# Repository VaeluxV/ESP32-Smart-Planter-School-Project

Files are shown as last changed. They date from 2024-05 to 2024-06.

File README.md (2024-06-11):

# ESP32 Smart Planter
## Hardware info
### Required Hardware:
* ESP32 Devkit (30-pins)
* Soil moisture sensor
* PN532 rfid reader
* Passive buzzer
* LDR
* Ds18b20 Soil temperature sensor
* Water Level Sensor
* Bme280
* 5V 4-channel relay module (a 2-channel module can also be used if you do not plan to add more hardware yourself)
* I2C LCD (min. 4 lines, 20 characters per line)
* Wire
### Optional hardware:
* Custom PCB (gerber files can be found under [`/CustomPCB/Gerber`](https://github.com/VaeluxV/ESP32-Smart-Planter-School-Project/tree/main/CustomPCB/Gerber) and eagle schematics under [`/Eagle/ESP-Planter`](https://github.com/VaeluxV/ESP32-Smart-Planter-School-Project/tree/main/Eagle/ESP-Planter))

## Software info

### Required software:
* Arduino IDE or VS Code (Platformio) (originally developed for/using Platformio)

### Required libraries:
* SPI
* Adafruit_PN532
* Wire
* LiquidCrystal_I2C
* Adafruit_Sensor
* Adafruit_BME280
* FastLED
* OneWire
* DallasTemperature
* WiFi
* PubSubClient
* freertos/FreeRTOS
* freertos/task

### The code:
You can find the code for the ESP32 under [`/src/main.cpp`](https://github.com/VaeluxV/ESP32-Smart-Planter-School-Project/blob/main/src/main.cpp)

---

## Other info

This project works using Grafana, InfluxDB & MQTT installed on any device such as a Raspberry Pi. You can remove the Grafana & InfluxDB if you do not need to store any data but it is not recommended because I have not tested the full functionality without these programs. MQTT is required if you do not modify any code.

Make sure to enter your WiFi and MQTT details when uploading this code to your ESP32 or it won't work!

MQTT settings can be found at line 18-21 and WiFi settings can be found at line 32-33.
Other configurable settings can also be found near the top of the code. This can be used if your LCD has a different I2C adress (line 44) for example.

The InfluxDB connection requires a database names `planter_readings` to be present so make sure to make that before starting the MQTT bridge!

Connections schematic (default config):
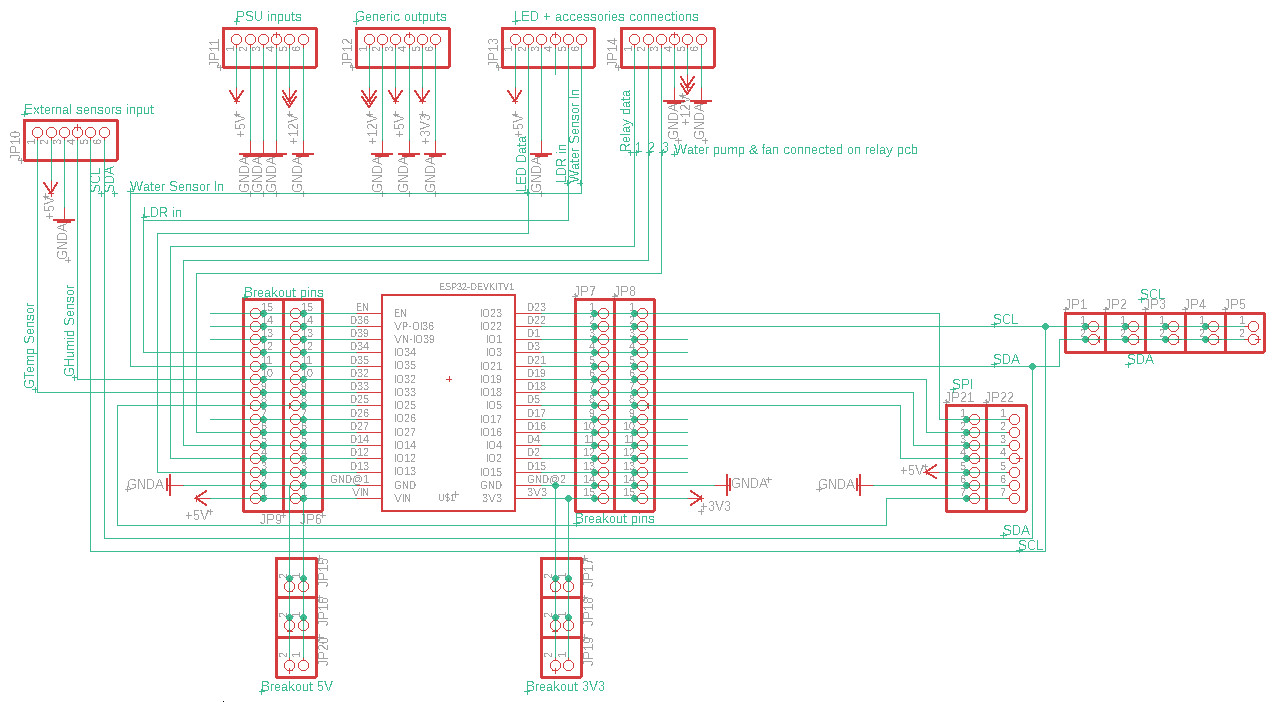
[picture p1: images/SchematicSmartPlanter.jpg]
Image of the schematic

Please note that the 12v & 5v connections are external connections coming from a 12v PSU (& buck converter for the 5v) while the 3.3v is delivered by the ESP32's internal power conversion.

---

### Relays and 12v components
The 5v relay module, 12v fan & 12v water pump are not shown in this schematic but have to be connected too. The fan is connected to relay channel 1, while the pump is connected on channel 2. All of these share a common ground with the esp32 (through the buck converter).

### Debugging connection
Debugging can be done over serial (9600 baud) using the USB connection. Make sure to still plug in the PSU as otherwise there will not be enough power to run everything and the ESP32 will possibly fail to boot properly!

---

You are free to open issues if you have any questions about something not documented here or otherwise not mentioned.

GLHF!

~ Vaelux

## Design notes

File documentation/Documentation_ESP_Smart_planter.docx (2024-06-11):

# ESP Smart Planter – Documentation

Below are pictures of the custom PCB

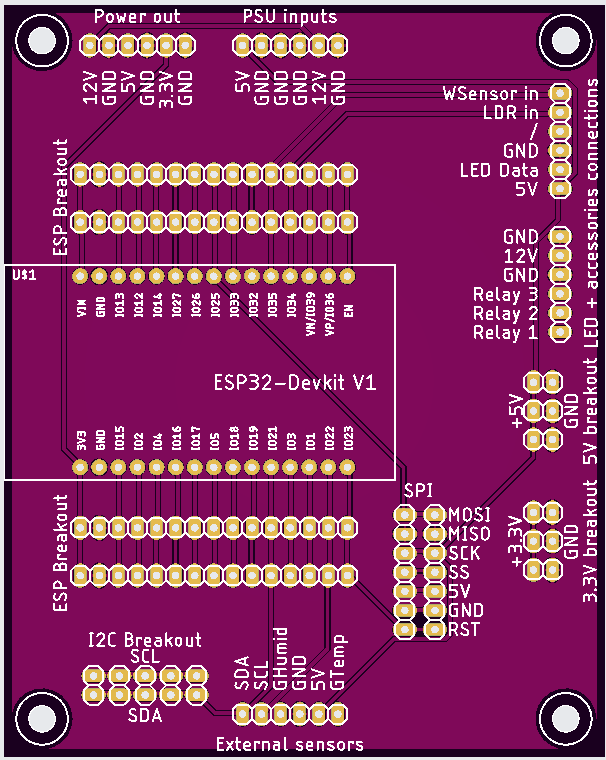
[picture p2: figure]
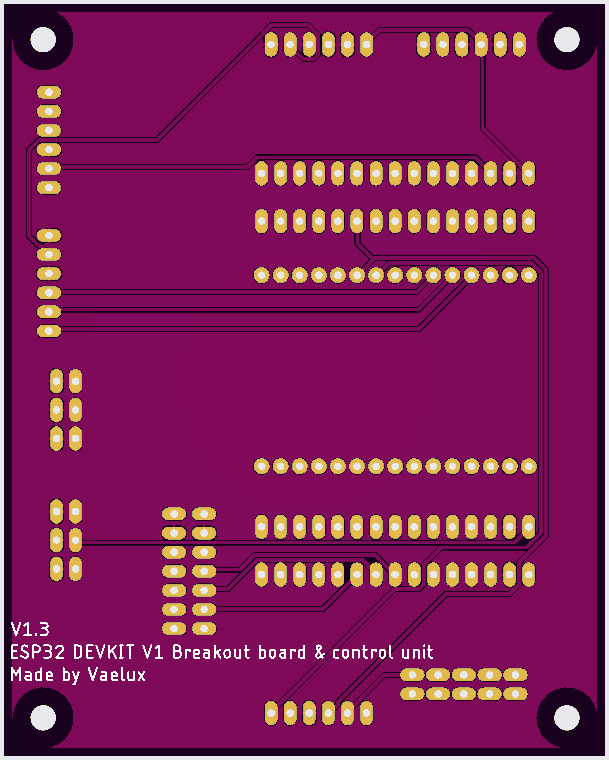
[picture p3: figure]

# Hardware:

- ESP32 Devkit v1 (30 pins)
- PN532 RFID reader
- LDR
- (Capacitive) soil moisture sensor
- I2C 20x4 LCD
- Passive buzzer (or speaker)
- Ds18b20 soil temperature sensor
- BME280
- WS2812B LED (COB) strip
- 4-channel (5v) relay module
- Water pump (12v)
- Fan (12v)
- Power supply (12v)
- Step-down buck converter (12 -> 5v or a variable variant if it can output 5v)
- Wires

# The software:

- Grafana
- InfluxDB
- Python (MQTT -> InfluxDB)
- C++ firmware (for ESP32)

# The Grafana setup

In Grafana we add the data source ‘InfluxDB’ using the created credentials and localhost because the database is running on the same device as the Grafana server.

We can then use graphs to display the temperatures and light values as well as use labels to display statuses of, for example, the fan or lights.

The ESP32 sends the following data:

- Air temperature
- Soil temperature
- Soil moisture
- Light level
- Water level
- Fan status
- Lights status
- Pump Status
- Current target (which plant)

All these datapoints are named appropriately in the influxdb.

# Installing the software and hardware

You can flash the ESP32 using PlatformIO or the Arduino IDE.
Make sure to have all the required libraries installed!

All the required libraries are listed at the top of the C++ code.

If you are unsure of what pins to connect the sensors to, refer to the code or the provided schematic to see what sensors connect to which pins.

Please make sure to change the WiFi SSID, Password & MQTT details BEFORE flashing the firmware to the board!
These can be found near the top of the code with the appropriately defined variables “WIFI_SSID”, “WIFI_PASSWORD”, “mqtt_server”, “mqtt_port”, “mqtt_username” & “mqtt_password”.

If you connect your sensors to other pins, you can change those too. All sensors are defined somewhere at the top portion of the code.

I recommend you either solder screw terminals to the PCB or solder wires that connect the sensors to the PCB, any other (semi-) permanent way is fine too except for breadboards as the tend to get some bad connections or disconnected wires sometimes.

# Important info:

Please refer to the sensor datasheets as some sensors should not be connected to the input of the ESP32 directly but instead need a pullup resistor or other special adjustments.
These resistors are not shown in the schematic but are required to be present for the planter to work properly.

If your fan is not 12v but instead a 5v fan you can use the positive from the buck converter instead of the 12v wire, so you don’t blow up your fan motor.

Refer to the documentation of each service such as Grafana or MQTT on how to set it up.

If the ESP32 is no longer sending data, please check if your WiFi network is still available. Unplug the ESP32 immediately if it gets wet! If the ESP32 is unresponsive, unplug wait a few moments and plug it in again to force it to reboot and reconnect.

Schematics and other info can be found on the GitHub repository, please refer to the ReadMe file on there for the locations of these.

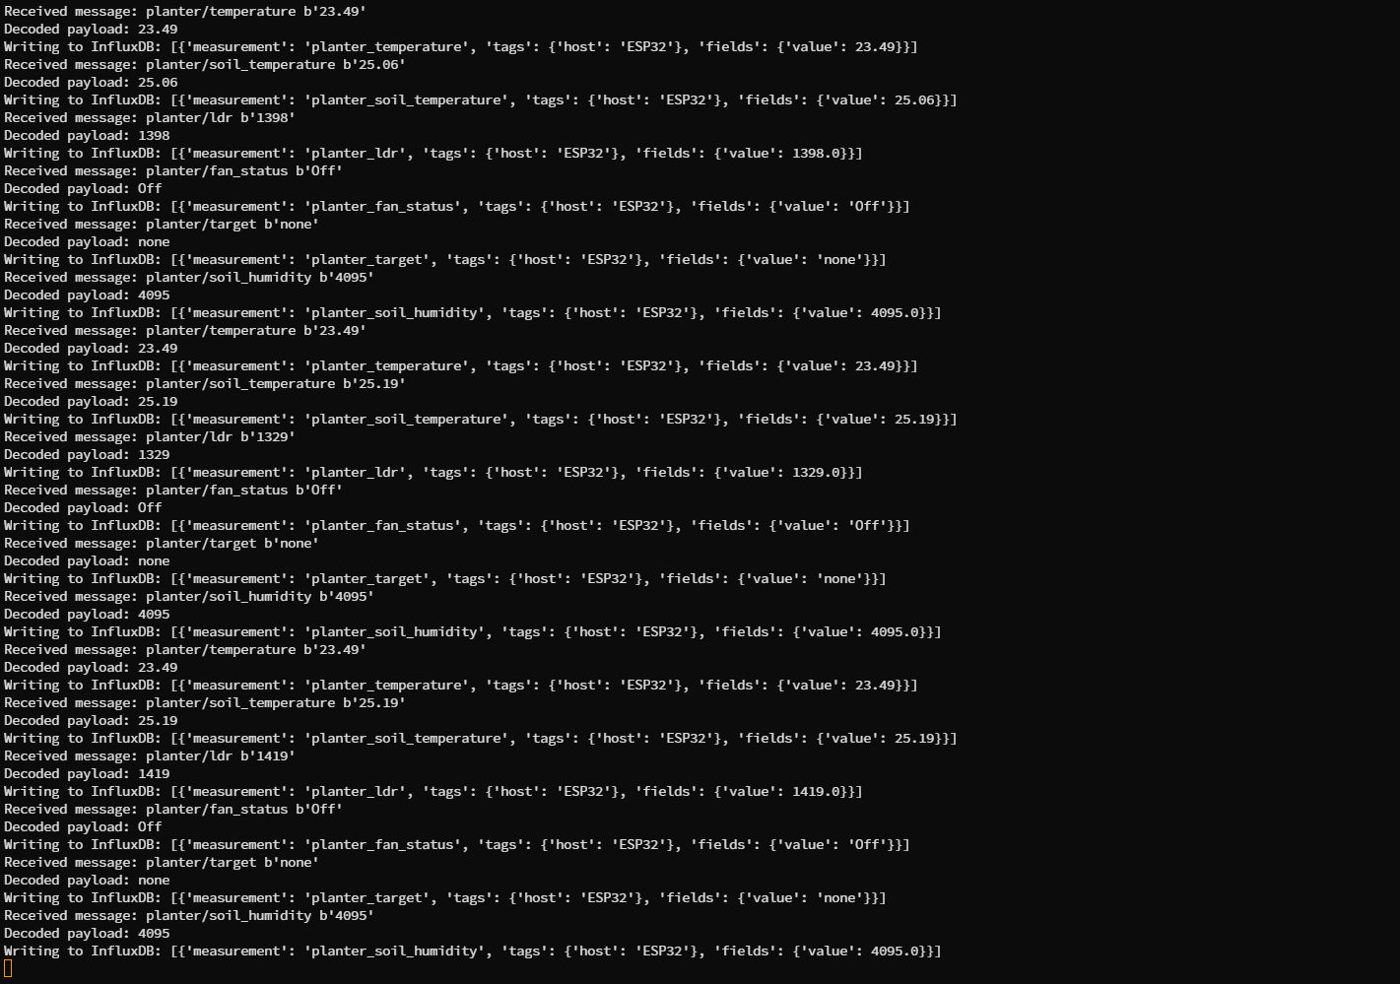
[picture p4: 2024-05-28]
images/Screenshot 2024-05-28 172759.png

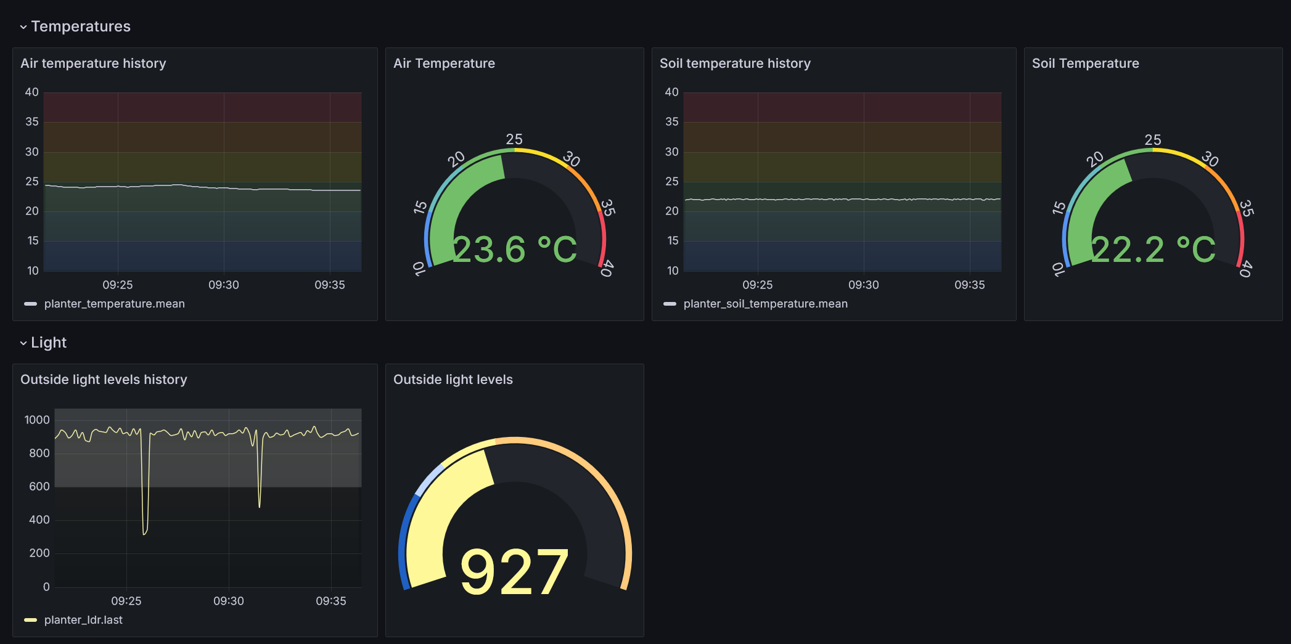
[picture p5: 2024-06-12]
Screenshot 2024-06-12 093641.png

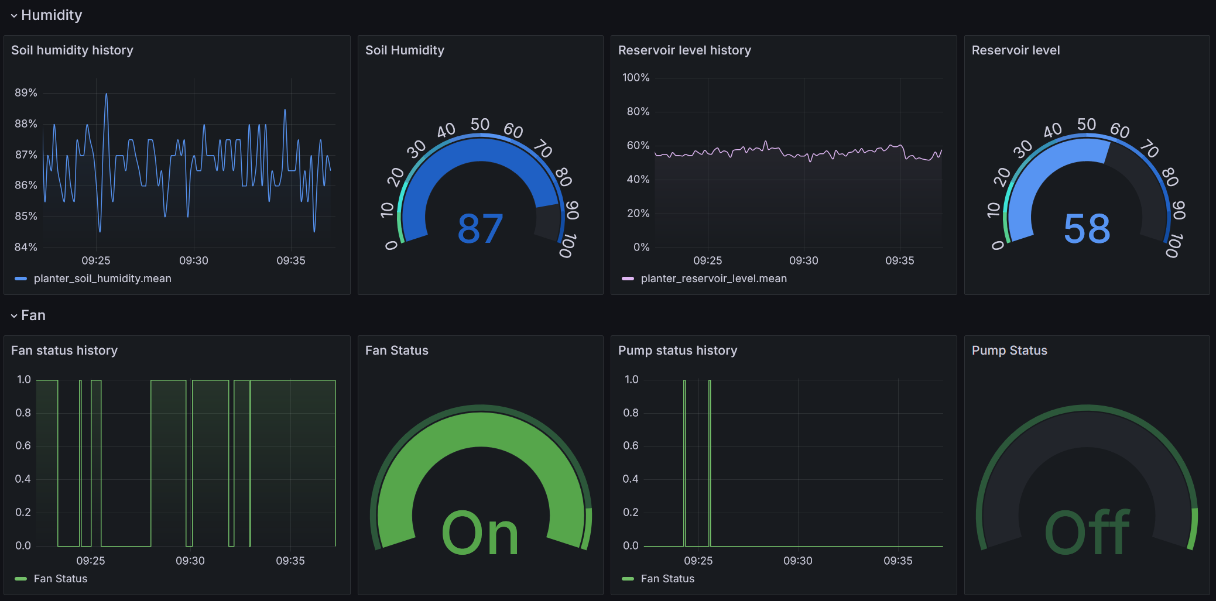
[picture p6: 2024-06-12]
Screenshot 2024-06-12 093723.png

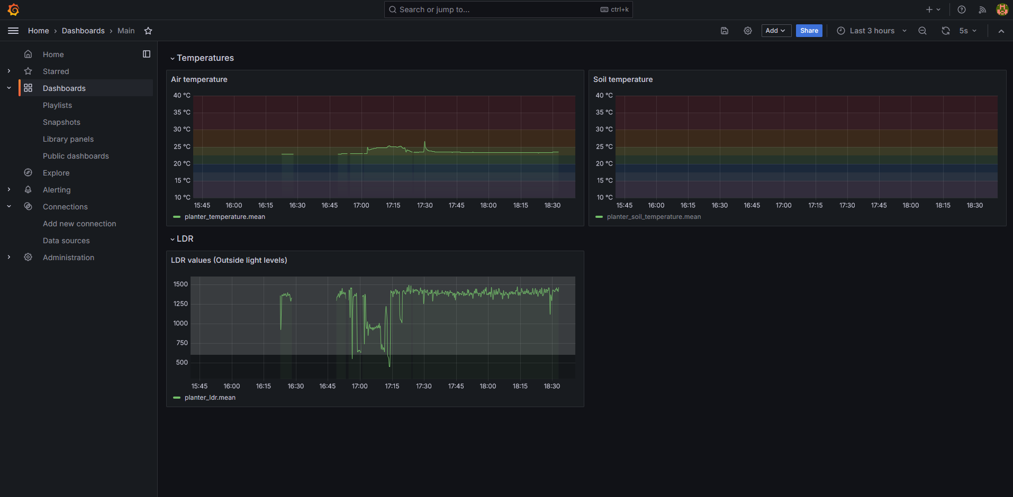
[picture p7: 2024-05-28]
Screenshot 2024-05-28 184053.png

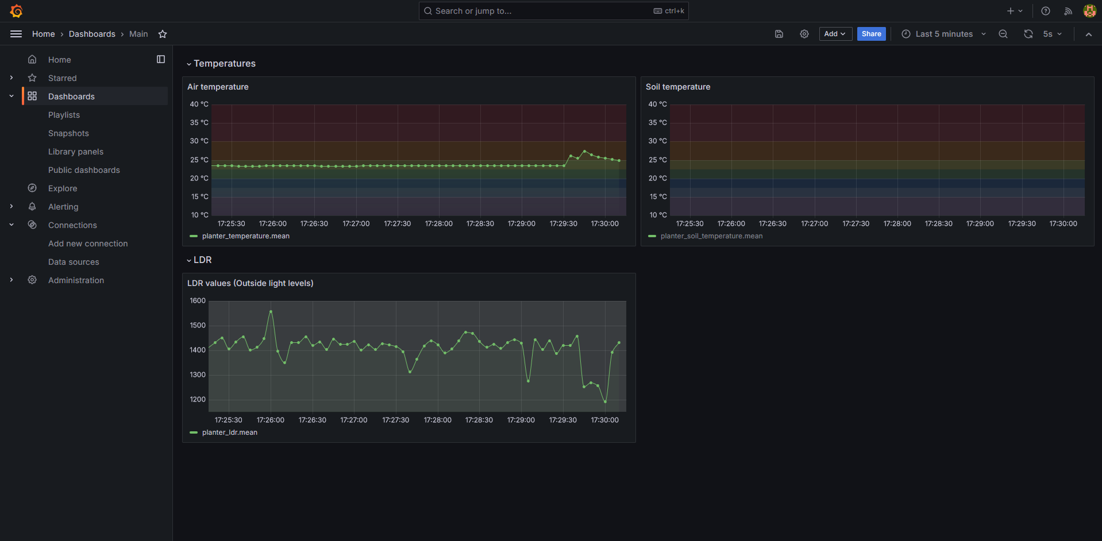
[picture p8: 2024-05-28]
images/Screenshot 2024-05-28 173021.png

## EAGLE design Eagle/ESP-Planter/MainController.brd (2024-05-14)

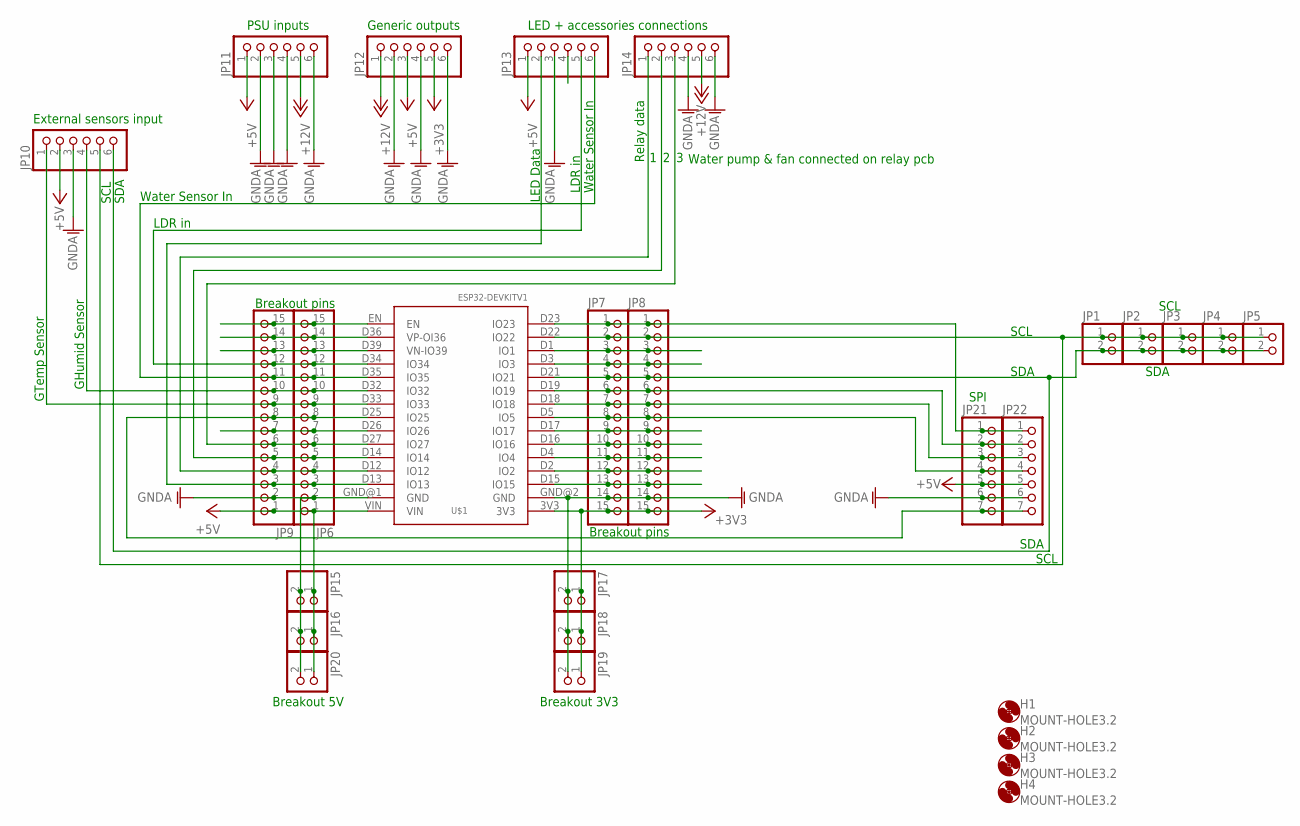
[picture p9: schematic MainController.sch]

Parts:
H1, H2, H3, H4: MOUNT-HOLE3.2; 3,2
JP1, JP2, JP3, JP4, JP5, JP15, JP16, JP17, JP18, JP19, JP20: PINHD-1X2; 1X02
JP6, JP7, JP8, JP9: PINHD-1X15; 1X15
JP10, JP11, JP12, JP13, JP14: PINHD-1X6; 1X06
JP21, JP22: PINHD-1X7; 1X07
U$1: ESP32DEVKITV1; ESP32-DEVKITV1

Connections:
+3V3: JP7.15, JP8.15, JP12.5, JP17.1, JP18.1, JP19.1, U$1.3V3
+5V: JP6.1, JP9.1, JP10.2, JP11.1, JP12.3, JP13.1, JP15.1, JP16.1, JP20.1, JP21.5, JP22.5, U$1.VIN
+12V: JP11.5, JP12.1, JP14.5
GNDA: JP6.2, JP7.14, JP8.14, JP9.2, JP10.3, JP11.2, JP11.3, JP11.4, JP11.6, JP12.2, JP12.4, JP12.6, JP13.3, JP14.4, JP14.6, JP15.2, JP16.2, JP17.2, JP18.2, JP19.2, JP20.2, JP21.6, JP22.6, U$1.GND@1 (GND), U$1.GND@2 (GND)
unnamed: JP6.10, JP9.10, JP10.4, U$1.D32 (IO32)
unnamed: JP6.9, JP9.9, JP10.1, U$1.D33 (IO33)
unnamed: JP7.9, JP8.9, U$1.D17 (IO17)
unnamed: JP6.7, JP9.7, U$1.D26 (IO26)
unnamed: JP7.6, JP8.6, JP21.2, JP22.2, U$1.D19 (IO19)
unnamed: JP7.1, JP8.1, JP21.1, JP22.1, U$1.D23 (IO23)
unnamed: JP6.13, JP9.13, U$1.D39 (VN-IO39)
unnamed: JP6.14, JP9.14, U$1.D36 (VP-OI36)
unnamed: JP6.15, JP9.15, U$1.EN
unnamed: JP1.1, JP2.1, JP3.1, JP4.1, JP5.1, JP7.2, JP8.2, JP10.5, U$1.D22 (IO22)
unnamed: JP6.3, JP9.3, JP13.2, U$1.D13 (IO13)
unnamed: JP6.12, JP9.12, JP13.5, U$1.D34 (IO34)
unnamed: JP7.3, JP8.3, U$1.D1 (IO1)
unnamed: JP7.4, JP8.4, U$1.D3 (IO3)
unnamed: JP1.2, JP2.2, JP3.2, JP4.2, JP5.2, JP7.5, JP8.5, JP10.6, U$1.D21 (IO21)
unnamed: JP6.4, JP9.4, JP14.1, U$1.D12 (IO12)
unnamed: JP6.5, JP9.5, JP14.2, U$1.D14 (IO14)
unnamed: JP7.8, JP8.8, JP21.4, JP22.4, U$1.D5 (IO5)
unnamed: JP7.10, JP8.10, U$1.D16 (IO16)
unnamed: JP7.11, JP8.11, U$1.D4 (IO4)
unnamed: JP7.12, JP8.12, U$1.D2 (IO2)
unnamed: JP7.13, JP8.13, U$1.D15 (IO15)
unnamed: JP6.11, JP9.11, JP13.6, U$1.D35 (IO35)
unnamed: JP6.8, JP9.8, JP21.7, JP22.7, U$1.D25 (IO25)
unnamed: JP7.7, JP8.7, JP21.3, JP22.3, U$1.D18 (IO18)
unnamed: JP6.6, JP9.6, JP14.3, U$1.D27 (IO27)

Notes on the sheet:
PSU inputs
Generic outputs
LED + accessories connections
LED Data
Relay data
External sensors input
SDA
SCL
GTemp Sensor
GHumid Sensor
Water Sensor In
Breakout pins
LDR in
Water pump & fan connected on relay pcb
Breakout 5V
Breakout 3V3
SPI

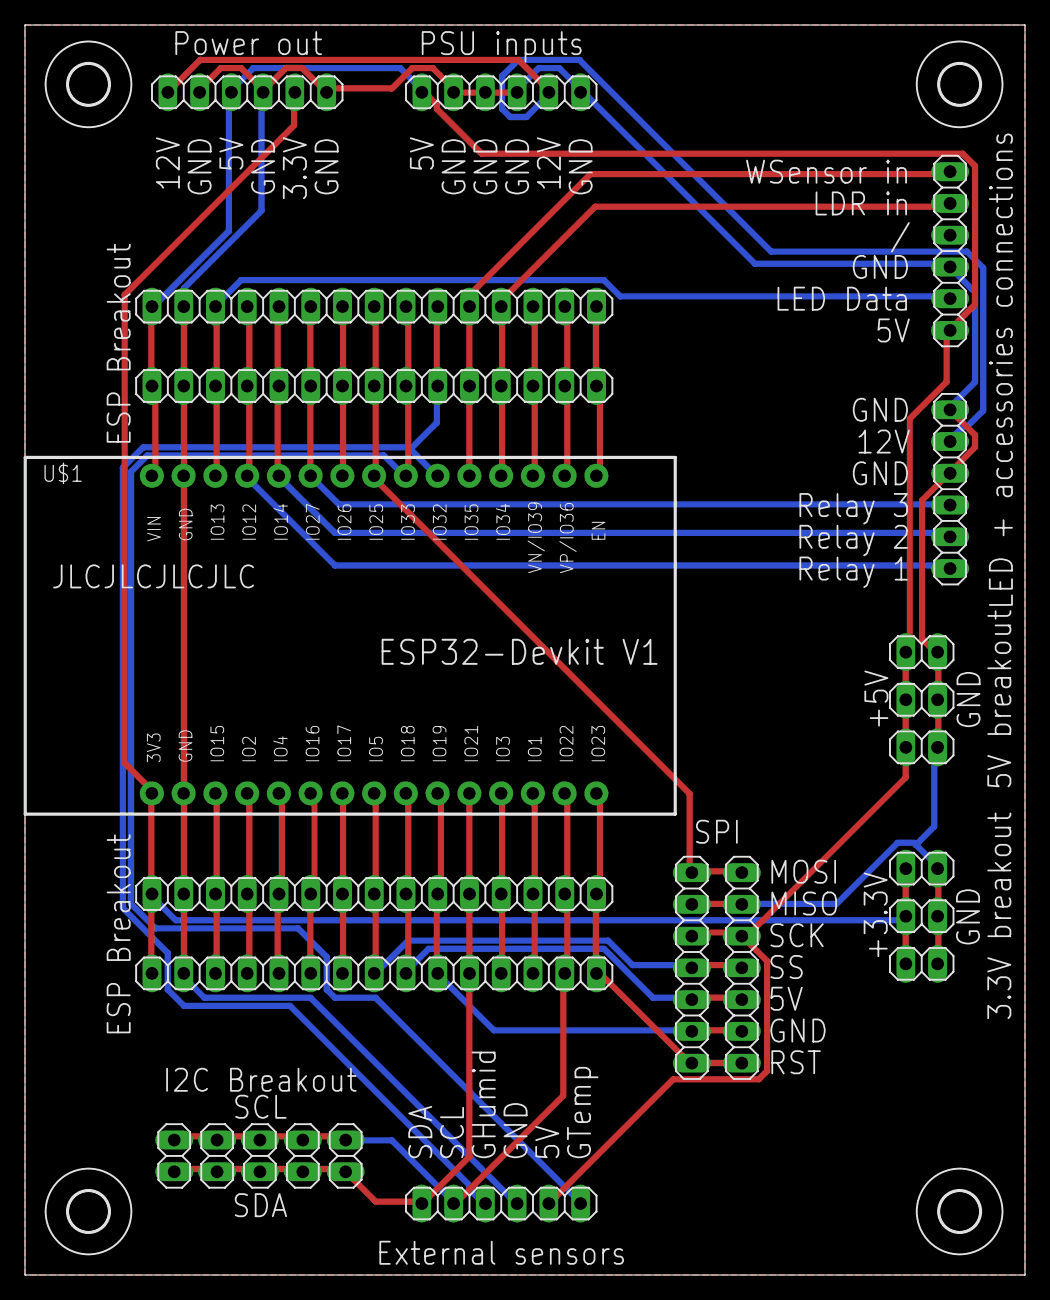
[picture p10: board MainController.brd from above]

Board: 2 copper layers, 80.0 x 100.0 mm, 27 parts (0 on the bottom side), 30 nets.

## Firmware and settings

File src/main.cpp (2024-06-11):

/* --- Libraries --- */
#include <Arduino.h>
#include <SPI.h>
#include <Adafruit_PN532.h>
#include <Wire.h>
#include <LiquidCrystal_I2C.h>
#include <Adafruit_Sensor.h>
#include <Adafruit_BME280.h>
#include <FastLED.h>
#include <OneWire.h>
#include <DallasTemperature.h>
#include <WiFi.h>
#include <PubSubClient.h>
#include <freertos/FreeRTOS.h>
#include <freertos/task.h>

// MQTT settings
#define mqtt_server "nebulabit.local"
#define mqtt_port 1883
#define mqtt_username "test"
#define mqtt_password "test"

// MQTT topics
#define TOPIC_TEMP "planter/temperature"
#define TOPIC_SOIL_TEMP "planter/soil_temperature"
#define TOPIC_LDR "planter/ldr"
#define TOPIC_FAN_STATUS "planter/fan_status"
#define TOPIC_PUMP_STATUS "planter/pump_status"
#define TOPIC_TARGET "planter/target"
#define TOPIC_SOIL_HUMIDITY "planter/soil_humidity"
#define TOPIC_RESERVOIR_LEVEL "planter/reservoir_level"

// WiFi settings
#define WIFI_SSID "SSID"
#define WIFI_PASSWORD "PASS"

// OneWire bus (soil temperature sensor)
#define ONE_WIRE_BUS 33
// Setup a oneWire instance to communicate with any OneWire devices
OneWire oneWire(ONE_WIRE_BUS);

// Pass the oneWire reference to the Dallas Temperature sensor
DallasTemperature sensors(&oneWire);

// LCD stuff
#define LCD_ADDRESS 0x27

#define LCD_COLUMNS 20
#define LCD_ROWS 4

LiquidCrystal_I2C lcd(LCD_ADDRESS, LCD_COLUMNS, LCD_ROWS);

//SPI (RFID reader) stuff
#define SS_PIN   5 // Set the SPI SS PIN
#define SCK_PIN  18
#define MOSI_PIN 23
#define MISO_PIN 19
#define RST_PIN  25 // Set the PN532 RST PIN

Adafruit_PN532 nfc(SCK_PIN, MISO_PIN, MOSI_PIN, SS_PIN);

// unsigned long previousTempMillis = 0;  // Variable to store the last time temperature was printed
// const long tempInterval = 1000;         // Interval at which to print temperature (in milliseconds)

//Buzzer
#define BUZZER_PIN 26 // Define the pin number for the buzzer

// BME 280
#define SEALEVELPRESSURE_HPA (1013.25)

#define BME280_ADDRESS 0x76 // BME280 I2C address

Adafruit_BME280 bme;

// LDR
#define LDR_PIN 34 // Define the pin connected to the LDR

// LED strip
#define LED_PIN 13
#define NUM_LEDS 100

CRGB leds[NUM_LEDS];

// Relay stuff
#define RELAY_CH1 12
#define RELAY_CH2 14
#define RELAY_CH3 27

#define RELAY_POWER 15

// Soil humidity sensor
#define SOIL_HUMIDITY_PIN 32

#define WATER_LEVEL_PIN 35

// Variables to store current target, etc.
String currentTarget = "none";

int ldrValue;

// Tell the lights when to turn on or off, if they turn off or on at unexpected times, try to tweak this value until it works for you.
#define LDR_TRIGGER 600

// Variables for temperature and other things that have to be stored globally
float temperature;

float soilTempC;

bool fanStatus = false;
bool pumpStatus = false;

float soilHumidity;

float waterLevel;

// Create an instance of the WiFi and MQTT client
WiFiClient espClient;
PubSubClient client(espClient);

// Function prototypes
void rfidTask(void *parameter);
void lcdTask(void *parameter);
void lcdHeading();
void ldrCheck();
void relayLogic();
void setup_wifi();
void reconnect();
void sendMQTTData();

void setup() {
  // set all the pins to the correct modes
  pinMode(RELAY_CH1, OUTPUT);
  pinMode(RELAY_CH2, OUTPUT);
  pinMode(RELAY_CH3, OUTPUT);
  pinMode(RELAY_POWER, OUTPUT);

  pinMode(SOIL_HUMIDITY_PIN, INPUT);
  pinMode(WATER_LEVEL_PIN, INPUT);

  //disable the relay channels by default
  digitalWrite(RELAY_CH1, HIGH);
  digitalWrite(RELAY_CH2, HIGH);
  digitalWrite(RELAY_CH3, HIGH);
  digitalWrite(RELAY_POWER, LOW); // Disable power for relay at startup to prevent issues

  // start serial communication
  Serial.begin(9600);
  Serial.println("Hello!");

  // Initialize the I2C communication
  Wire.begin(); // SDA pin 21, SCL pin 22

  // Initialize the LCD
  lcd.init();
  // Turn on the lcd backlight
  lcd.backlight();

  lcdHeading();

  // Initialize the DS18B20 sensor
  sensors.begin();

  // Initialize the RFID reader
  nfc.begin();

  // print RFID reader info on serial console and show if there is one present or not on the LCD & serial monitor
  uint32_t versiondata = nfc.getFirmwareVersion();
  if (!versiondata) {
    Serial.print("Didn't find PN53x board");
    lcd.setCursor(0, 3);
    lcd.print("Didn't find PN53x!");
    while (1); // Halt
  }

  // Got good data, print it. (firmware version & chip type)
  Serial.print("Found chip PN5"); Serial.println((versiondata >> 24) & 0xFF, HEX);
  Serial.print("Firmware ver. "); Serial.print((versiondata >> 16) & 0xFF, DEC);
  Serial.print('.'); Serial.println((versiondata >> 8) & 0xFF, DEC);

  lcd.setCursor(0, 3);
  lcd.print("Found RFID reader!");
  delay(250);

  // Configure board to read RFID tags
  nfc.SAMConfig();
  Serial.println("Waiting for an RFID card...");
  lcd.clear();

  lcdHeading();
  lcd.setCursor(0, 3);
  lcd.print("Found RFID reader!  ");

  delay(500);

  // check if the BME280 sensor is present, if not wait and try again until one is found
  while (!bme.begin(BME280_ADDRESS)) {
    Serial.println("Could not find a valid BME280 sensor, check wiring!");
    lcd.setCursor(0, 3);
    lcd.print("No valid BME280!    ");
    delay(500);
  }

  lcd.setCursor(0, 3);
  lcd.print("BME280 found!       ");

  delay(500);

  // start wifi conection
  setup_wifi();
  client.setServer(mqtt_server, mqtt_port);

  FastLED.addLeds<WS2812B, LED_PIN, GRB>(leds, NUM_LEDS); // Activate LEDs

  lcd.clear();
  lcdHeading();

  // Create task for RFID reading
  xTaskCreatePinnedToCore(
    rfidTask,          // Task function
    "RFID Task",       // Task name
    10000,             // Stack size (words)
    NULL,              // Task parameter
    1,                 // Priority
    NULL,              // Task handle
    0                  // Core to run the task on (0 or 1)
  );

  xTaskCreatePinnedToCore(
    lcdTask,          // Task function
    "RFID Task",       // Task name
    10000,             // Stack size (words)
    NULL,              // Task parameter
    2,                 // Priority
    NULL,              // Task handle
    1                 // Core to run the task on (0 or 1)
  );

  delay(100);
  // enable relay again
  digitalWrite(RELAY_POWER, HIGH);
}

void loop() {
  // handle disconnects
  if (!client.connected()) {
    reconnect();
  }

  client.loop();


  unsigned long currentTime = millis(); // Get the current time in milliseconds

  relayLogic();

  ldrCheck();

  // Get soil temperatures
  sensors.requestTemperatures();
  soilTempC = sensors.getTempCByIndex(0);
  temperature = bme.readTemperature();
  soilHumidity = map(analogRead(SOIL_HUMIDITY_PIN), 0, 4095, 100, 0);
  waterLevel = analogRead(WATER_LEVEL_PIN);

  // Debug print temperatures
  Serial.print("Soil temperature: ");
  Serial.print(soilTempC);
  Serial.println(" °C");

  Serial.print("Air temperature: ");
  Serial.print(temperature);
  Serial.println(" °C");

  Serial.print("Soil humidity: ");
  Serial.println(soilHumidity);

  Serial.print("Water level: ");
  Serial.println(waterLevel);

  sendMQTTData(); // send teh data over MQTT

  delay(5000);

}

void setup_wifi() {
  delay(10);
  Serial.println();
  Serial.print("Connecting to ");
  Serial.println(WIFI_SSID);

  WiFi.begin(WIFI_SSID, WIFI_PASSWORD);

  while (WiFi.status() != WL_CONNECTED) {
    delay(500);
    Serial.print(".");
  }

  Serial.println("");
  Serial.println("WiFi connected");
  Serial.println("IP address: ");
  Serial.println(WiFi.localIP());
}

void reconnect() {
  while (!client.connected()) {
    Serial.print("Attempting MQTT connection...");
    if (client.connect("ESP32Client", mqtt_username, mqtt_password)) {
      Serial.println("connected");
    } else {
      Serial.print("failed, rc=");
      Serial.print(client.state());
      Serial.println(" try again in 5 seconds");
      delay(5000);
    }
  }
}

void sendMQTTData() {
  client.publish(TOPIC_TEMP, String(temperature).c_str());
  client.publish(TOPIC_SOIL_TEMP, String(soilTempC).c_str());
  client.publish(TOPIC_LDR, String(ldrValue).c_str());
  client.publish(TOPIC_RESERVOIR_LEVEL, String(map(waterLevel, 0, 4095, 0, 100)).c_str());
  if (fanStatus) {
    client.publish(TOPIC_FAN_STATUS, String("1").c_str());
  } else if (!fanStatus) {
    client.publish(TOPIC_FAN_STATUS, String("0").c_str());
  }
  if (pumpStatus) {
    client.publish(TOPIC_PUMP_STATUS, String("1").c_str());
  } else if (!pumpStatus) {
    client.publish(TOPIC_PUMP_STATUS, String("0").c_str());
  }
  client.publish(TOPIC_TARGET, currentTarget.c_str());
  client.publish(TOPIC_SOIL_HUMIDITY, String(soilHumidity).c_str());
}


void relayLogic() {
  if(currentTarget == "Strawberries" & temperature > 23){
    digitalWrite(RELAY_CH1, LOW);
    fanStatus = true;
  } else if(currentTarget == "Strawberries" & temperature <= 21){
    digitalWrite(RELAY_CH1, HIGH);
    fanStatus = false;
  } else if(currentTarget == "Tomatoes" & temperature > 28){
    digitalWrite(RELAY_CH1, LOW);
    fanStatus = true;
  } else if(currentTarget == "Tomatoes" & temperature <= 24){
    digitalWrite(RELAY_CH1, HIGH);
    fanStatus = false;
  } else if(currentTarget == "Cabbage" & temperature > 21){
    digitalWrite(RELAY_CH1, LOW);
    fanStatus = true;
  } else if(currentTarget == "Cabbage" & temperature <= 18){
    digitalWrite(RELAY_CH1, HIGH);
    fanStatus = false;
  } else {
    digitalWrite(RELAY_CH1, HIGH);
    fanStatus = false;
  }
}

void lcdHeading() {
  lcd.setCursor(0, 0);
  lcd.print("ESP32 Smart planter");
}

void buzzerAccept() {
  tone(BUZZER_PIN, 950);
  delay(75);
  noTone(BUZZER_PIN);
  delay(50);
  tone(BUZZER_PIN, 1150);
  delay(75);
  noTone(BUZZER_PIN);
  delay(300);
}

void buzzerDeny() {
  tone(BUZZER_PIN, 600);
  delay(60);
  noTone(BUZZER_PIN);
  delay(40);
  tone(BUZZER_PIN, 550);
  delay(60);
  noTone(BUZZER_PIN);
  delay(40);
  tone(BUZZER_PIN, 500);
  delay(60);
  noTone(BUZZER_PIN);
  delay(240);
}

void ldrCheck() {
  ldrValue = analogRead(LDR_PIN); // Read the analog value from the LDR
  Serial.print("LDR Value: ");
  Serial.println(ldrValue); // Print the value to the serial monitor
  if (int(ldrValue) < LDR_TRIGGER - 50) {
    fill_solid(leds, NUM_LEDS, CRGB(100, 10, 255)); // color
  FastLED.show();
  } else if (int(ldrValue) > LDR_TRIGGER + 50) {
    fill_solid(leds, NUM_LEDS, CRGB(10, 1, 20)); // dark
  FastLED.show();
  }
}

void lcdTask(void *parameter) {
  while(1){
    lcd.clear();
    lcdHeading();
    lcd.setCursor(0, 1);
    lcd.print("Current air temp:");
    lcd.setCursor(0, 2);
    lcd.print(String(temperature) + " *C");

    delay(2500);

    lcd.clear();
    lcdHeading();
    lcd.setCursor(0, 1);
    lcd.print("Current soil temp:");
    lcd.setCursor(0, 2);
    lcd.print(String(soilTempC) + " *C");

    delay(2500);

    lcd.clear();
    lcdHeading();
    lcd.setCursor(0, 1);
    lcd.print("Current target:");
    lcd.setCursor(0, 2);
    lcd.print(String(currentTarget));

    delay(2500);

    lcd.clear();
    lcdHeading();
    lcd.setCursor(0, 1);
    lcd.print("Current light level:");
    lcd.setCursor(0, 2);
    if(ldrValue > LDR_TRIGGER){
      lcd.print("Daytime");
    } else if(ldrValue <= LDR_TRIGGER){
      lcd.print("Nighttime");
    }

    delay(2500);

    lcd.clear();
    lcdHeading();
    lcd.setCursor(0, 1);
    lcd.print("Fan status:");
    lcd.setCursor(0, 2);
    if(fanStatus == true){
      lcd.print("Running");
    } else if(fanStatus == false){
      lcd.print("Off");
    }

    delay(2500);
  
  }
  vTaskDelay(2500 / portTICK_PERIOD_MS); // Delay for 2500ms before checking again
}

void rfidTask(void *parameter) {
  while (1) {
    // Check for an RFID card
    uint8_t success;
    uint8_t uid[] = { 0, 0, 0, 0, 0, 0, 0 }; // Buffer to store the returned UID
    uint8_t uidLength; // Length of the UID (4 or 7 bytes depending on ISO14443A card type)

    success = nfc.readPassiveTargetID(PN532_MIFARE_ISO14443A, uid, &uidLength);

    if (success) {
      Serial.println("Found an RFID card!");
      lcd.clear();
      lcdHeading();
      lcd.setCursor(0, 1);
      lcd.print("Found an RFID card!");

      Serial.print("UID Length: ");
      Serial.print(uidLength, DEC);
      Serial.println(" bytes");
      Serial.print("UID Value: ");
      for (uint8_t i = 0; i < uidLength; i++) {
        Serial.print(" 0x");
        Serial.print(uid[i], HEX);
      }
      Serial.println("");

      // Define the authorized UIDs
      uint8_t showCurrentTarget[] = {0x53, 0x2D, 0x1A, 0x19};
      uint8_t resetTarget[] = {0xD3, 0x1E, 0x1C, 0x19};

      uint8_t runPump[] = {0x93, 0xEC, 0x11, 0x19};

      uint8_t tomatoesUID[] = {0x13, 0x27, 0x13, 0x19};
      uint8_t cabbageUID[] = {0xF3, 0x47, 0xD, 0x19};
      uint8_t StrawberriesUID[] = {0x43, 0x7A, 0xF, 0x19};

      // Compare the UID of the card with authorized UIDs
      if (memcmp(uid, tomatoesUID, uidLength) == 0) {
        Serial.println("Tomatoes");
        lcd.clear();
        lcdHeading();

        lcd.setCursor(0, 1);
        lcd.print("Target set:");
        lcd.setCursor(0, 2);
        lcd.print("Tomatoes");

        currentTarget = "Tomatoes";

        buzzerAccept();

        delay(1000);

        noTone(BUZZER_PIN);
        digitalWrite(BUZZER_PIN, LOW);

      } else if (memcmp(uid, cabbageUID, uidLength) == 0) {
        Serial.println("Cabbage");
        lcd.clear();
        lcdHeading();

        lcd.setCursor(0, 1);
        lcd.print("Target set:");
        lcd.setCursor(0, 2);
        lcd.print("Cabbage");

        currentTarget = "Cabbage";

        buzzerAccept();

        delay(1000);

        noTone(BUZZER_PIN);
        digitalWrite(BUZZER_PIN, LOW);

      } else if (memcmp(uid, StrawberriesUID, uidLength) == 0) {
        Serial.println("Strawberries");
        lcd.clear();
        lcdHeading();

        lcd.setCursor(0, 1);
        lcd.print("Target set:");
        lcd.setCursor(0, 2);
        lcd.print("Strawberries");

        currentTarget = "Strawberries";

        buzzerAccept();

        delay(1000);

        noTone(BUZZER_PIN);
        digitalWrite(BUZZER_PIN, LOW);

      } else if (memcmp(uid, showCurrentTarget, uidLength) == 0) {
        Serial.println("showing target on lcd");
        lcd.clear();
        lcdHeading();
        lcd.setCursor(0, 1);
        lcd.print("Current target:");
        lcd.setCursor(0, 2);
        lcd.print(String(currentTarget));

        buzzerAccept();

        delay(1000);

        noTone(BUZZER_PIN);
        digitalWrite(BUZZER_PIN, LOW);
        
      } else if (memcmp(uid, resetTarget, uidLength) == 0) {
        Serial.println("reset target");
        lcd.clear();
        lcdHeading();

        lcd.setCursor(0, 1);
        lcd.print("Target reset.");

        currentTarget = "none";

        buzzerAccept();

        delay(1000);

        noTone(BUZZER_PIN);
        digitalWrite(BUZZER_PIN, LOW);
        
      } else if (memcmp(uid, runPump, uidLength) == 0) {
        Serial.println("running pump.");

        digitalWrite(RELAY_CH2, LOW);
        pumpStatus = true;

        buzzerAccept();

        delay(5000);

        digitalWrite(RELAY_CH2, HIGH);
        pumpStatus = false;

        noTone(BUZZER_PIN);
        digitalWrite(BUZZER_PIN, LOW);
        
      } else {
        Serial.println("Error");
        lcd.clear();
        lcdHeading();

        lcd.setCursor(0, 1);
        lcd.print("Error, unrecognised.");

        buzzerDeny();

        delay(1000);

        noTone(BUZZER_PIN);
        digitalWrite(BUZZER_PIN, LOW);

      }
    }
    vTaskDelay(100 / portTICK_PERIOD_MS); // Delay for 100ms before checking again
  }
}

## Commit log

2024-05-13 Stuck on RFID read & added soil temp
    [main.cpp]
2024-05-13 Working RFID + keeps track of plant type
2024-05-13 added LDR + leds
2024-05-14 added relay channels
2024-05-14 Add LCD task + delayed start of relay
2024-05-14 Add PCB + update documentation
2024-05-14 added eagle schematic
    [MainController.brd, MainController.sch]
2024-06-09 Added water level sensor + manual water pump
2024-06-09 Add schematic picture
2024-06-11 Add pump status + fixed fan status
    [main.cpp]
2024-06-11 Support fan & pump status properly
2024-06-11 Pump status displays/sends correctly
    [main.cpp]
2024-06-11 Fix humidity reading being inverted
    [main.cpp]
